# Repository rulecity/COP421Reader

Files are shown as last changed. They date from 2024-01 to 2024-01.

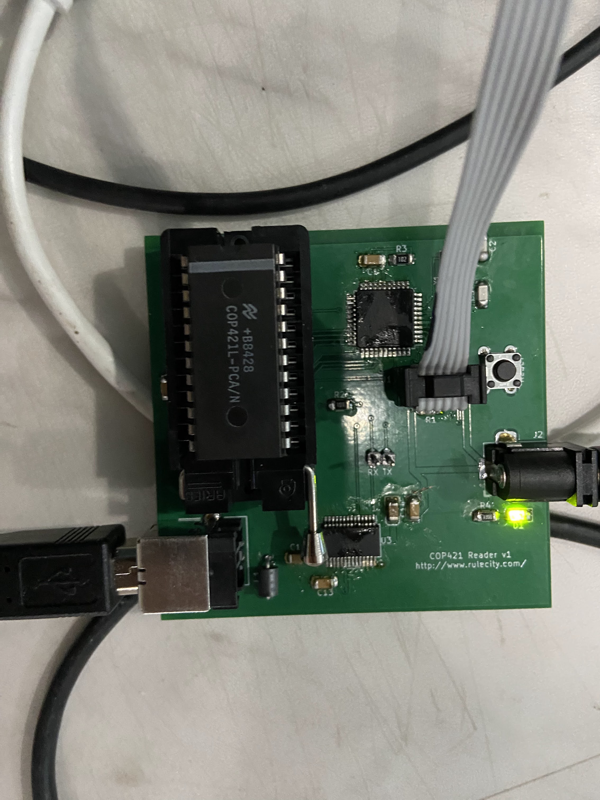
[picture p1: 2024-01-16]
COPReaderFinishedExample.jpg

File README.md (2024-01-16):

# COP421Reader
This is a hardware reader for the COP421 Microcontroller.

I designed it very quickly just to read the COP421 microcontroller used by the RDI Halcyon (since I have/had one temporarily on loan).  It turns out it's identical to the Thayer's Quest arcade COP421 program, but it's nice to know for sure.

I relied heavily on the information at this page to contruct my reader: http://john.ccac.rwth-aachen.de:8000/patrick/COPSreader.htm

## Building
### KiCad files
I started with an EAGLE project that I made for Star Rider for this PCB, so you will see references to Star Rider in the Kicad project.  I imported some EAGLE symbols and used some native Kicad symbols so you'll see a hybrid of both.  (like I said, this was a quick n' dirty project since I intended it to only be used once).  I used KiCad v6 for this project.

### AVR files
Source code for the ATMega644p microcontroller, as well as a Makefile and a script to install via AVR Dragon / AVRDude.
The AVR reads from the COP421 and outputs the resulting data to USB serial port.

### Desktop
Source code to build a simple desktop (Windows/Linux/Mac) application to read the data from the AVR (via USB serial port) and save to a file.

### Bill of Materials
CSV file showing which parts I used on the PCB.

## Running
- Put COP421 into ZIF socket in custom PCB.
- Power on custom PCB with 5V wall wart.
- Plug in USB cable from desktop device (Windows/Linux/Mac) into custom PCB.  The USB serial device should be registered automatically.
- Run the desktop command line application.  You should see a "Listening" prompt.
- Hit the RESET button on the custom PCB.
- After a few seconds, the desktop app should report CRC success or fail.  On success, it will report the file path that it has written the dumped binary to.  You may repeat this (by repeatedly pressing RESET) to confirm that you've got a consistent read.

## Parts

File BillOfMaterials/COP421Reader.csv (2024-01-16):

Index | Manufacturer Part Number | Manufacturer Name | Description | Attrition % | Requested Quantity 1 | Pack Quantity 1 | Pack Type 1 | Digi-Key Part Number 1 | Unit Price 1 | Extended Price 1 | Minimum Order Quantity 1 | Customer Reference
1 | 24-6554-10 | Aries Electronics | CONN IC DIP SOCKET ZIF 24POS TIN |  | 1 | 1 | Tube | A300-ND | 13.33000 | $13.33 | 1 | U2
2 | 292304-1 | TE Connectivity AMP Connectors | CONN RCPT USB2.0 TYPEB 4POS R/A |  | 1 | 1 | Tray | A31725-ND | 2.19000 | $2.19 | 1 | X5
3 | 2761001112 | Fair-Rite Products Corp. | FERRITE BEAD 53 OHM AXIAL 1LN |  | 1 | 1 | Cut Tape (CT) | 1934-1423-1-ND | 0.19000 | $0.19 | 1 | L1
4 | ECS-184-20-3X-TR | ECS Inc. | CRYSTAL 18.4320MHZ 20PF SMD |  | 1 | 1 | Cut Tape (CT) | XC1777CT-ND | 0.35000 | $0.35 | 1 | Y1
5 | FT232RL-REEL | FTDI, Future Technology Devices International Ltd | IC USB FS SERIAL UART 28-SSOP |  | 1 | 1 | Cut Tape (CT) | 768-1007-1-ND | 4.80000 | $4.80 | 1 | U3
6 | ATMEGA644PA-AU | Microchip Technology | IC MCU 8BIT 64KB FLASH 44TQFP |  | 1 | 1 | Tray | ATMEGA644PA-AU-ND | 6.44000 | $6.44 | 1 | U1
7 | CC1206KRX7R9BB103 | YAGEO | CAP CER 10000PF 50V X7R 1206 |  | 1 | 1 | Cut Tape (CT) | 311-1174-1-ND | 0.21000 | $0.21 | 1 | C10
8 | C1206C200J5GAC7800 | KEMET | CAP CER 20PF 50V C0G/NP0 1206 |  | 2 | 2 | Cut Tape (CT) | 399-C1206C200J5GAC7800CT-ND | 0.41000 | $0.82 | 1 | C2,C3
9 | CL31B475KAHNNNE | Samsung Electro-Mechanics | CAP CER 4.7UF 25V X7R 1206 |  | 1 | 1 | Cut Tape (CT) | 1276-1055-1-ND | 0.18000 | $0.18 | 1 | C15
10 | 0901310123 | Molex | CONN HEADER VERT 6POS 2.54MM |  | 1 | 1 | Tray | WM8121-ND | 0.99000 | $0.99 | 1 | J1
11 | RC1206JR-0710KL | YAGEO | RES 10K OHM 5% 1/4W 1206 |  | 1 | 1 | Cut Tape (CT) | 311-10KERCT-ND | 0.10000 | $0.10 | 1 | R1
12 | RC1206JR-071KL | YAGEO | RES 1K OHM 5% 1/4W 1206 |  | 1 | 1 | Cut Tape (CT) | 311-1.0KERCT-ND | 0.10000 | $0.10 | 1 | R3
13 | RC1206JR-07100RL | YAGEO | RES 100 OHM 5% 1/4W 1206 |  | 1 | 1 | Cut Tape (CT) | 311-100ERCT-ND | 0.10000 | $0.10 | 1 | R2
14 | B3F-1020 | Omron Electronics Inc-EMC Div | SWITCH TACTILE SPST-NO 0.05A 24V |  | 1 | 1 | Bulk | SW402-ND | 0.38000 | $0.38 | 1 | S1
15 | CL31B104KBCNNNC | Samsung Electro-Mechanics | CAP CER 0.1UF 50V X7R 1206 |  | 4 | 4 | Cut Tape (CT) | 1276-1017-1-ND | 0.11000 | $0.44 | 1 | C1, C4, C13, C14
16 | APT3216SGC | Kingbright | LED GREEN CLEAR CHIP SMD |  | 1 | 1 | Cut Tape (CT) | 754-1141-1-ND | 0.32000 | $0.32 | 1 | LED
17 | PJ-002A | CUI Devices | CONN PWR JACK 2X5.5MM SOLDER |  | 1 | 1 | Bag | CP-002A-ND | 0.61000 | $0.61 | 1 | J2
18 | ERJ-8ENF3300V | Panasonic Electronic Components | RES SMD 330 OHM 1% 1/4W 1206 |  | 1 | 1 | Cut Tape (CT) | P330FCT-ND | 0.18000 | $0.18 | 1 | R4

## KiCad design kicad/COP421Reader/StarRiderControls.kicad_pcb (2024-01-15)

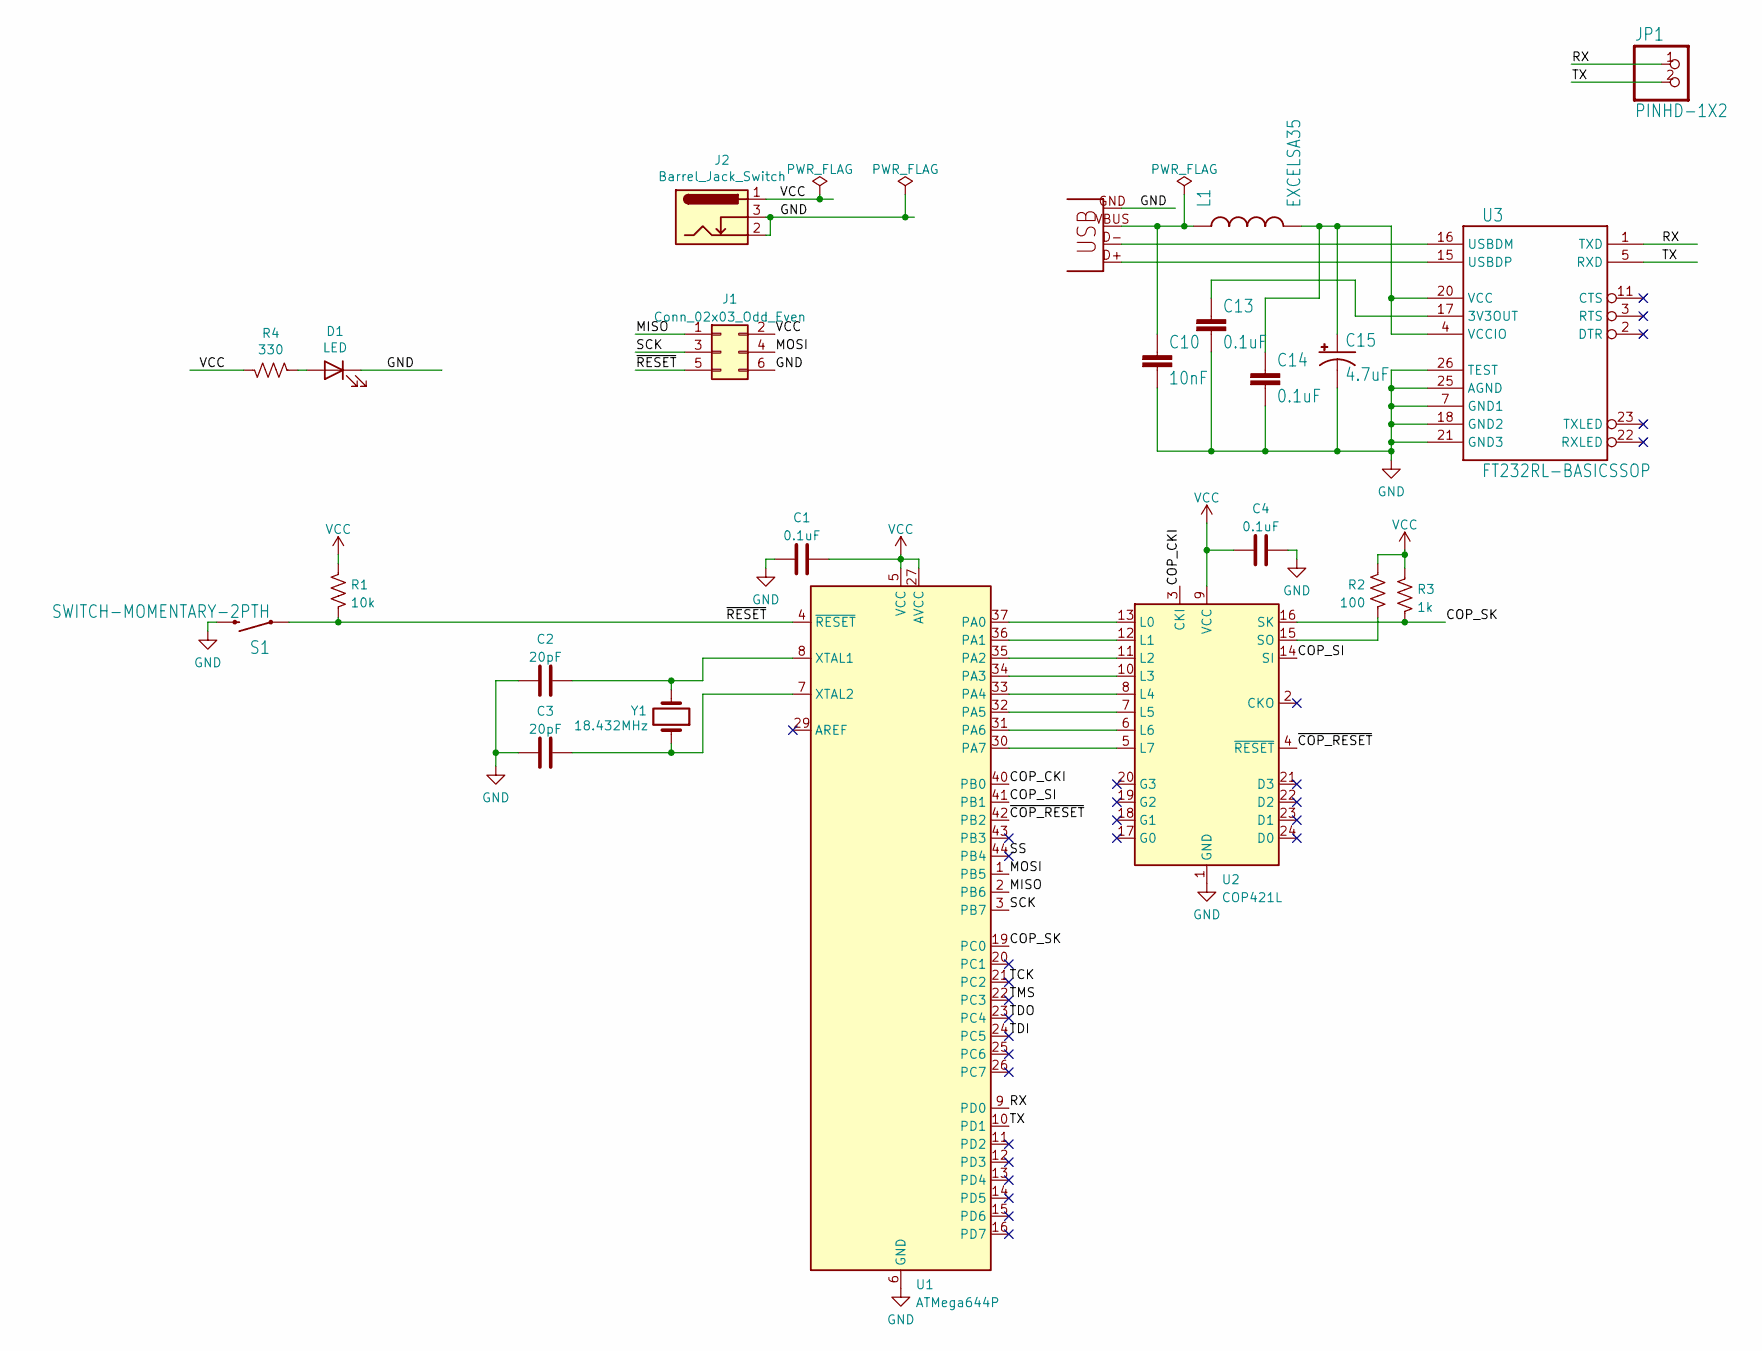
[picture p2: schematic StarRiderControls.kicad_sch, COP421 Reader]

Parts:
C1, C4, C13, C14: 0.1uF; C_1206_3216Metric_Pad1.33x1.80mm_HandSolder
C2, C3: 20pF; C_1206_3216Metric_Pad1.33x1.80mm_HandSolder
C10: 10nF; C_1206_3216Metric_Pad1.33x1.80mm_HandSolder
C15: 4.7uF; EIA3216
D1: LED; LED_1206_3216Metric_Pad1.42x1.75mm_HandSolder
J1: Conn_02x03_Odd_Even; PinHeader_2x03_P2.54mm_Vertical
J2: Barrel_Jack_Switch; BarrelJack_Horizontal
JP1: PINHD-1X2; 1X02
L1: EXCELSA35
R1: 10k; R_1206_3216Metric_Pad1.30x1.75mm_HandSolder
R2: 100; R_1206_3216Metric_Pad1.30x1.75mm_HandSolder
R3: 1k; R_1206_3216Metric_Pad1.30x1.75mm_HandSolder
R4: 330; R_1206_3216Metric_Pad1.30x1.75mm_HandSolder
S1: SWITCH-MOMENTARY-2PTH; TACTILE-PTH
U1: ATMega644P; TQFP-44_10x10mm_P0.8mm
U2: COP421L; DIP-24_W15.24mm_Socket
U3: FT232RL-BASICSSOP; SSOP-28_5.3x10.2mm_P0.65mm
X5: USBPTH; USB-B-PTH
Y1: 18.432MHz; CRYSTAL-CSM-3X

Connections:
/COP_CKI: U1.40 (PB0), U2.3 (CKI)
/COP_SI: U1.41 (PB1), U2.14 (SI)
/COP_SK: R3.2, U1.19 (PC0), U2.16 (SK)
/MISO: J1.1, U1.2 (PB6)
/MOSI: J1.4, U1.1 (PB5)
/RX: JP1.1, U1.9 (PD0), U3.1 (TXD)
/SCK: J1.3, U1.3 (PB7)
/SS: U1.44 (PB4)
/TCK: U1.21 (PC2)
/TDI: U1.24 (PC5)
/TDO: U1.23 (PC4)
/TMS: U1.22 (PC3)
/TX: JP1.2, U1.10 (PD1), U3.5 (RXD)
/~COP_RESET: U1.42 (PB2), U2.4 (~RESET)
/~RESET: J1.5, R1.2, S1.1, U1.4 (~RESET)
GND: C1.2, C2.2, C3.2, C4.1, C10.2, C13.2, C14.2, C15.C (-), D1.1 (K), J1.6, J2.2, J2.3, S1.3 (2), U1.6 (GND), U1.18 (GND), U1.28 (GND), U1.39 (GND), U2.1 (GND), U3.7 (GND1), U3.18 (GND2), U3.21 (GND3), U3.25 (AGND), U3.26 (TEST), X5.GND
unnamed: C2.1, U1.8 (XTAL1), Y1.2
unnamed: C3.1, U1.7 (XTAL2), Y1.1
unnamed: C10.1, L1.P1 (1), X5.VBUS
unnamed: C13.1, U3.17 (3V3OUT)
unnamed: C14.1, C15.A (+), L1.P2 (2), U3.4 (VCCIO), U3.20 (VCC)
unnamed: D1.2 (A), R4.2
unnamed: R2.1, U2.15 (SO)
unnamed: U1.30 (PA7), U2.5 (L7)
unnamed: U1.31 (PA6), U2.6 (L6)
unnamed: U1.32 (PA5), U2.7 (L5)
unnamed: U1.33 (PA4), U2.8 (L4)
unnamed: U1.34 (PA3), U2.10 (L3)
unnamed: U1.35 (PA2), U2.11 (L2)
unnamed: U1.36 (PA1), U2.12 (L1)
unnamed: U1.37 (PA0), U2.13 (L0)
unnamed: U3.15 (USBDP), X5.D+
unnamed: U3.16 (USBDM), X5.D-
VCC: C1.1, C4.2, J1.2, J2.1, R1.1, R2.2, R3.1, R4.1, U1.5 (VCC), U1.17 (VCC), U1.27 (AVCC), U1.38 (VCC), U2.9 (VCC)

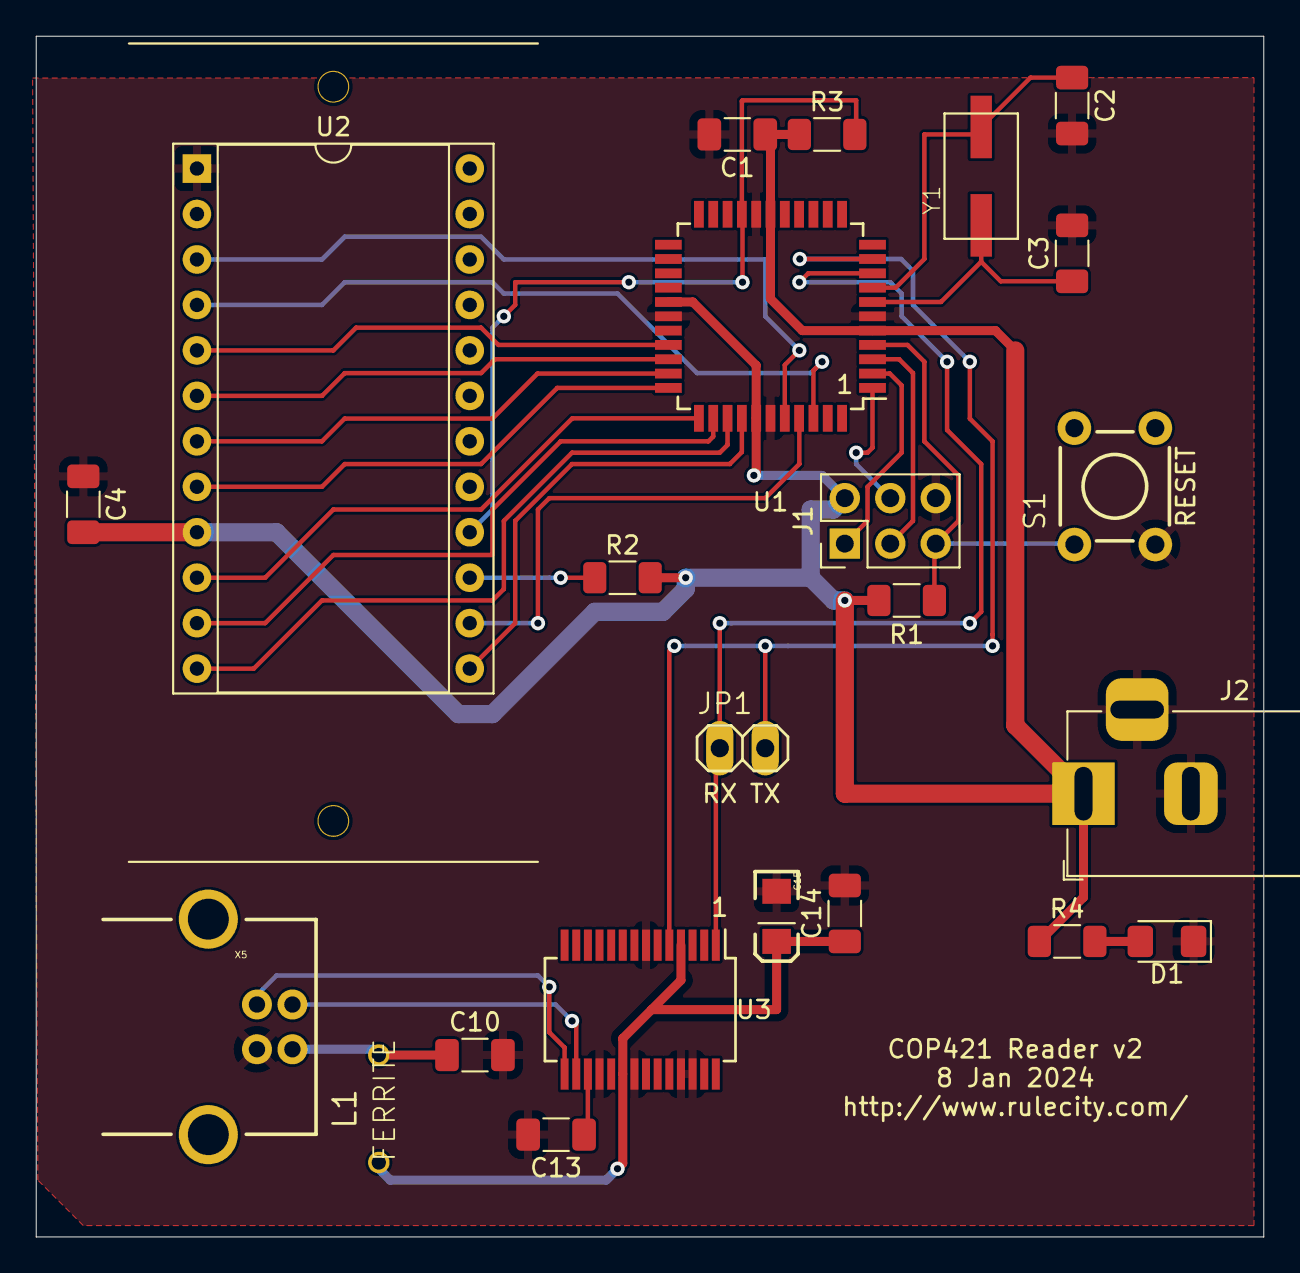
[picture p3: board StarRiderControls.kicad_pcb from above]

Board: 2 copper layers, 68.6 x 67.1 mm, 23 parts (0 on the bottom side), 29 nets.

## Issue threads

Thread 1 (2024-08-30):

Questions about how to program the COP421

Tachibana-Camellia, 2024-08-30:
@rulecity Thank you for your sharing, but I’ve encountered a small problem. After obtaining the .bin file of the internal program for the COP421, I’m not sure how to write it into a new COP421 chip. I’ve consulted the TI COP400 series data manual from that era, but it doesn’t mention this at all. I’m at a loss and have no choice but to seek your help. If you’re willing to provide me with some guidance, I would be extremely grateful. I apologize again for the inconvenience.
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

Tachibana-Camellia, 2024-08-30:
I thought I 've made a mistake. COP421 has a mask ROM which can't be programmed.

rulecity, 2024-08-30:
Yes, the COP421 can only be programmed one time, I assume at the factory.

Out of curiosity, how did you obtain the .bin file?  I assume you did not use my project, since some of the source code for the desktop application is missing.

Tachibana-Camellia, 2024-08-31:
One of my friends is attempting to replicate the Apple Lisa 2. He provided me with the assembly source code from the COP421 ROM, and the organizer of that source code is listed as Dr. Patrick Schäfer. So, I suspect he obtained the source code from Dr. Patrick's blog.

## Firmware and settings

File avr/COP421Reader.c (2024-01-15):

// COP421 Reader
// By Matt Ownby
// Jan 2024

// Very quick and dirty.  This was to read a single microcontroller so I just put enough effort into it to get it working.
// Thanks to http://john.ccac.rwth-aachen.de:8000/patrick/COPSreader.htm for doing most of the work and the excellent documentation.
// Final design's CKI runs at about 250 kHz and it still works.  I could've written this in assembly language and increased CKI speed but it wasn't worth it.

// This program dumps 1k bytes + 2 CRC bytes at 115200 bps over AVR's USART serial lines.

#include <stdio.h>
#include <avr/io.h> 
#include <avr/interrupt.h>
#include "serial.h"
#include "crc.h"

/////////////////////////////////////////////////////

#define WAIT_FALL()		while ((PINC & (1 << PC0)) != 0) { fastClockThink(); }
#define WAIT_RISE()		while ((PINC & (1 << PC0)) == 0) { fastClockThink(); }

//////////////////////////////////////

// to manage output clock that we generate
uint8_t g_u8COP421CkiIsHigh = 0;

// to hold buffer that we read from COP
uint16_t g_u16BufferCount = 0;
uint8_t *g_pBufferPtr = 0;
uint8_t g_arrCOPBuffer[1024];

inline void fastClockThink()
{
	// make fast clock tick
	if (TIFR0 & (1 << OCF0A))
	{
		g_u8COP421CkiIsHigh ^= 1;

		PORTB &= ~(1 << PB0);
		PORTB |= (g_u8COP421CkiIsHigh << PB0);

		TIFR0 |= (1 << OCF0A);	// clear CTC flag
	}
}

inline void insertByte(uint8_t u8Byte)
{
	PORTA = u8Byte;

	// wait for SK's next falling edge
	WAIT_FALL();

	// wait for SK's next rising edge
	WAIT_RISE();
}

int main (void) 
{
	uint8_t u8CyclesElapsed64k = 0;

	uint8_t u8Tmp = 0;

	serial_init();

	// Setup 16-bit timer
	TCCR1A = (1 << WGM11);	// enable CTC
	TCCR1B = (1 << CS10) | (1 << CS11);	// /64 prescaling
	OCR1B = 0xFFF0;	// ~64k worth of cycles

	// Setup 8-bit timer
	TCCR0A = (1 << WGM01);	// enable CTC
	TCCR0B = (1 << CS00);	// no-prescaling
	OCR0A = 36;	// CTC every 36 cycles (this makes outgoing clock run at about 250 kHz)

	// go into output mode for CKI, SI, and RESET
	DDRB = (1 << PB0) | (1 << PB1) | (1 << PB2);

	// set CKI, SI and RESET low
	PORTB = (0 << PB0) | (0 << PB1) | (0 << PB2);

	// go into input mode for SK
	DDRC = (0 << PC0);

	// start in input mode for L0-L7 to be safe
	DDRA = 0;

	// start tracking 16-bit timer so we know how many cycles have elapsed
	TCNT1 = 0;

	// enable interrupts now that we are initialized
	sei();

	///////////////////

	// POWER ON STAGE

	// played around with this value until I got a ~130ms setup time
	while (u8CyclesElapsed64k < 37)
	{
		fastClockThink();

		// if 64k cycles have elapsed
		if (TIFR1 & (1 << OCF1A))
		{
			TIFR1 |= (1 << OCF1A);	// clear CTC flag
			u8CyclesElapsed64k++;
		}
	}

	// wait for SK's next rising edge
	WAIT_RISE();

	// raise SI and RESET'
	PORTB |= (1 << PB1)|(1 << PB2);

	// wait for SK's next falling edge
	WAIT_FALL();

	// wait for SK's next rising edge
	WAIT_RISE();

	// at this point, the COP is ready for us to insert instructions

	DDRA = 0xFF;	// go into output mode

	// This sends the initial program needed to put the COP in "ROM dump" mode
	insertByte(0);	// CLRA
	insertByte(0x63);
	insertByte(0xFC);
	insertByte(0xBF);
	insertByte(0x44);
	insertByte(0x33);
	insertByte(0x64);

	// SPECIAL BEHAVIOR LAST INSERTED BYTE

	PORTA = 0x44;	// NOP

	// wait for SK's next falling edge
	WAIT_FALL();

	// NEED TO LOWER SI IN MIDDLE OF SK

	u8Tmp = 0;
	
	// SK period is 16 of our fast clocks, so we go at 11 at recommendation of blog post
	while (u8Tmp < 11)
	{
		// make fast clock tick
		if (TIFR0 & (1 << OCF0A))
		{
			g_u8COP421CkiIsHigh ^= 1;

			PORTB &= ~(1 << PB0);
			PORTB |= (g_u8COP421CkiIsHigh << PB0);

			TIFR0 |= (1 << OCF0A);	// clear CTC flag

			if (g_u8COP421CkiIsHigh)
			{
				u8Tmp++;
			}
		}
	}

	// PREPARE TO READ BYTES

	PORTB &= ~(1 << PB1);	// LOWER SI
	DDRA = 0;	// INPUT MODE FOR DATA BUS

	WAIT_RISE();

	// At this point, the first byte of the program will be put on the data bus as soon as SK falls

	g_pBufferPtr = g_arrCOPBuffer;
	g_u16BufferCount = 0;

	// read in the 1k program
	while (g_u16BufferCount < sizeof(g_arrCOPBuffer))
	{
		WAIT_FALL();
		
		// byte of program will be put on data bus shortly after this point; we'll wait until rising edge to guarantee that it's there

		WAIT_RISE();

		*g_pBufferPtr = PINA;

		g_pBufferPtr++;
		g_u16BufferCount++;
	}

	// go back into init/reset state for COP so it's not doing anything with the bus
	PORTB = (0 << PB0) | (0 << PB1) | (0 << PB2);

	// DUMP BUFFER OUT TO SERIAL PORT
	
	g_pBufferPtr = g_arrCOPBuffer;
	g_u16BufferCount = 0;
	crc_ccitt_init();

	while (g_u16BufferCount < sizeof(g_arrCOPBuffer))
	{
		uint8_t u8 = *g_pBufferPtr;
		tx_to_buf(u8);
		crc_ccitt_update(u8);
		g_pBufferPtr++;
		g_u16BufferCount++;
	}

	// send CRC value (lil endian)
	tx_to_buf(crc_ccitt_crc() & 0xFF);
	tx_to_buf(crc_ccitt_crc() >> 8);

	// program done!
	for (;;)
	{
	}
	
}

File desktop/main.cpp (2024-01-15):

#include <iostream>

#include <mpolib/SerialFactory.h>
#include "COPDumper.h"

int main(int argc, char **argv)
{
	if (argc == 2)
	{
		try
		{
			ISerialSPtr serial = SerialFactory::CreateInstance(argv[1]);

			auto *pDumper = new COPDumper(serial.get());
			serial->Init(115200, false);
			try
			{
				pDumper->DoIt();
			}
			catch (std::exception &ex)
			{
				fprintf(stderr, "Exception: %s", ex.what());
			}
			delete pDumper;
		}
		catch (std::exception &ex)
		{
			printf("Exception: %s\n", ex.what());
		}
	}
	else
	{
		printf("Command line: %s [path to serial device]\n", argv[0]);
        printf("Windows example of serial device: COM1\n");
        printf("Mac example of serial device: /dev/tty.usbserial-14620\n");
        printf("    (try 'ls -l /dev/*tty*serial*' to find a USB serial device)\n");
	}
	return 0;
}
